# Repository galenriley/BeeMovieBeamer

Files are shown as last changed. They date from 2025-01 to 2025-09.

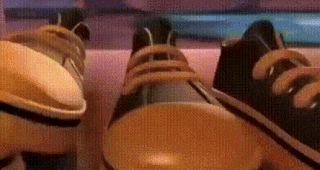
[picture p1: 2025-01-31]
assets/beemovie_wide.gif

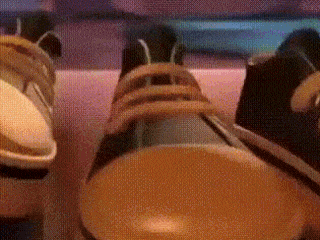
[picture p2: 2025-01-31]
assets/beemovie_full.gif

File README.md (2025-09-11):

# BeeMovieBeamer

A stupid gift for Junior  
based on a [tiktok from @jacuto](https://www.tiktok.com/@jacuto/video/7439527807316790574?lang=en)  
with help from Becca and Don (who don't want to be linked to)

## Safety/Disclaimers

I am an idiot that doesn't know what he is doing with microcontrollers! Lithium batteries are terrifying! And flammable!
It is highly recommended to gently unplug the battery when not in use and store it in a fire safe container away from anything combustible.

BeeMovieBeamer render

## Button Functions

Most functions are accessible via the startup screen. If you're "lost" during operation, press the power button once to restart the device.

- **Power Button** (located on the side of the device, near the USB port)  
  Press to reset/power on and go to the startup screen. Double press to power off.
- **Button 1** (located next to the screen, in the center)  
  Plays The Bee Movie once, then ~~puts the device to sleep~~ disables the screen backlight to conserve battery.
- **Button 2** (located next to the screen, on top if the USB port is oriented upward)  
  Vertically flips the display.  
  *This button only works on the startup screen.
- **Button 3** (located next to the screen, on the bottom if the USB port is oriented upward)  
  Plays The Bee Movie on loop until the device is reset using the Power Button or the battery dies.  
  *This button only works on the startup screen. 
- **Button 4** (located on the side of the device, near the USB port)  
  Resets the "Lifetime Bees Movied" counter on the startup screen.  
  Press once for conformation prompt. Press twice to reset the counter.  
  *This button only works on the startup screen.
  The case allows access to this button using a paperclip or sim ejector tool.

## Disassembly for Safe Storage
  
1. Remove the hand strap.
2. Insert a fingernail or prying tool in the slots on the side of the case.
3. Remove the back panel by sliding it out.
4. _Carefully_ lift the battery, slide out the battery tray, and unplug the battery cable.  
 
## Bill of Materials

- [LILYGO T4 v1.3 with 2.4 inch display](https://lilygo.cc/products/t4?variant=42405660393653)
Be sure to get the Q368 variant. The other is not compatible with the 3d printed case included in this project.
- 3.7V Lipo Batterywith JST GH 1.25mm plug, max dimensions 6.5mm x 40mm x 65mm
[I used this one and replaced the stock plug with one which came packaged with the LILYGO T4 board](https://www.amazon.com/dp/B07S75L945). You could buy a smaller battery with the right plug, and fill the leftover space in the case with some scrap foam to prevent it from rattling around.
- [This micro USB cable fits the case perfectly](https://a.co/d/34nNxp7)
- 1 inch nylon webbing strap and tri-glide buckle (or your own solution, elastic would also work)
- 2x M2 screws

You also need access to a computer to build and deploy the software, 3D printer(s), and you will likely need to solder the battery cable.

## Instructions to Make Your Own

### Buliding the Software
1. [Download and install Visual Studio Code](https://code.visualstudio.com/Download)
2. Open Visual Studio Code and [install PlatformIO IDE](https://platformio.org/install/ide?install=vscode)
3. [Download the project files from GitHub](https://github.com/galenriley/BeeMovieBeamer/archive/refs/heads/main.zip) and unzip somewhere on your computer.
4. From Visual Studio Code, click the PlatformIO icon on the left sidebar (it looks like an ant's head).
5. From the PlatformIO frame, click "Open Project" and navigate to the BeeMovieBeamer folder you unzipped earlier.
6. Connect the LILYGO T4 board to your computer via the micro usb port.
7. Near the bottom of Visual Studio Code, look for these icons. Mouse-over the Check icon, confirm the tooltip says "PlatformIO: Build", and click it.


8. After the Build process is complete, mouse over the Right Arrow icon, confirm the tooltip says "PlatformIO: Upload", and click it. Wait for the upload to complete and the board to reboot and show the software startup screen.

### Fabricating the Bee Movie Beamer
1. Find the 3D files in the project's "/case/" folder (you downloaded these already) and print using your preferred filament and settings. This is left as an exercise for the reader.
The case prints just fine with FDM, though the buttons are tiny and printing with resin would result in a better looking end product.
2. Sand/paint/seal/finish the parts as preferred.
Note: The clearances around the buttons are snug and you may need to sand away some material to achieve a satisfactory final fit, especially around the power button on the side.
3. Set the case on a stable surface and carefully position the buttons in their slots. Tweezers will come in handy.
4. Place the board in the case and secure with 2x screws.
5. If your battery didn't already have a 1.25mm plug, cut off the stock plug and solder the one which came packaged with the board.
Safety warning: Do not let the wires touch when soldering, for explosion and fire and pain reasons.
6. Plug in the battery, route the cable around the battery tray while installing it (the tray is to isolate the battery from being punctured by the IO pins on the board, you could also snip these pins off), and install the back lid of the case.
7. For the hand strap, feed the nylon webbing around the center bar of the triglide buckle and sew to itself.
8. On the case, feed the hand strap from the front to the back through one buckle, across the back lid, from the back to the front through the other buckle, and through both slots in the triglide. Adjust for your hand, cut to fit, then remove the strap to melt the raw end from fraying. Reinstall the strap.

Enjoy!

PS If you make this dumb thing, please tag Instagram @thatgalen, so I can see your creation!

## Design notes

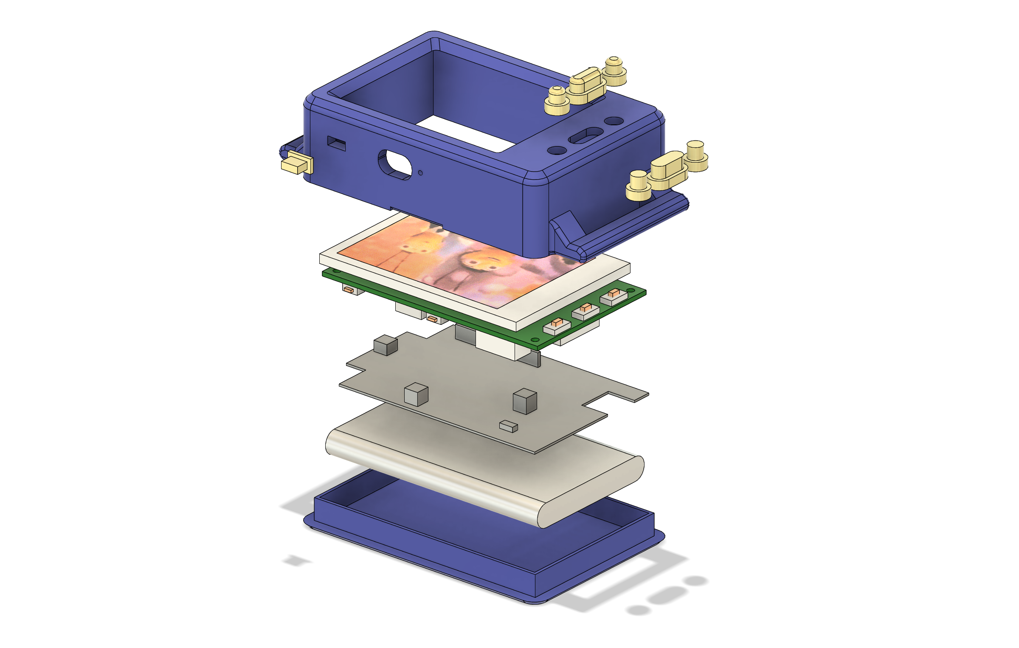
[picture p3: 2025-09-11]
case/exploded_view.png

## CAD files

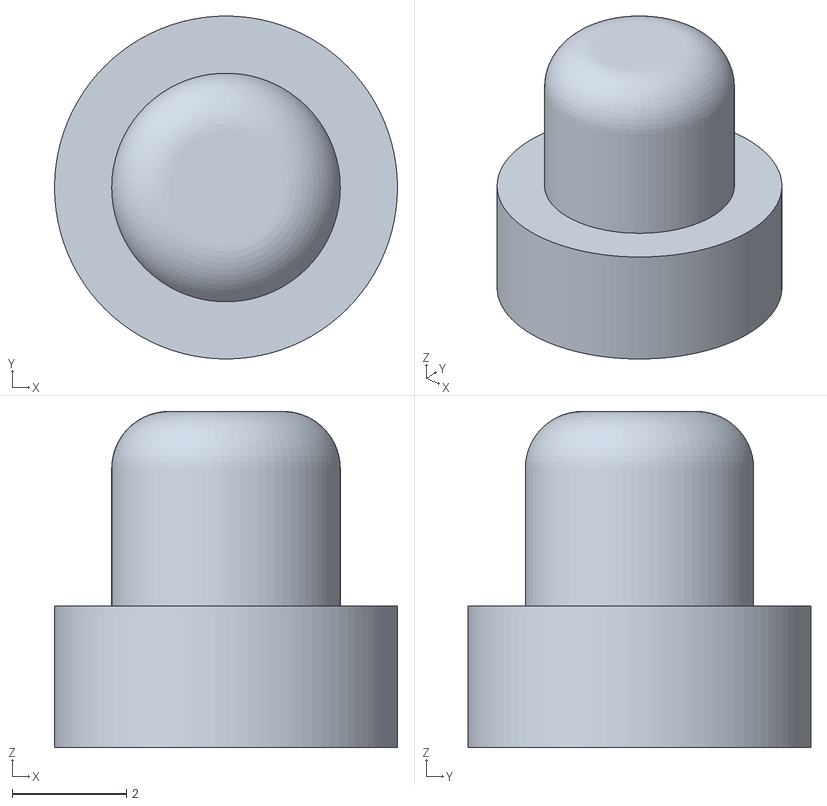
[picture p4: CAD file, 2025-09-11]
case/circle_button_rounded_print_two.stl
6.00 x 6.00 x 5.88

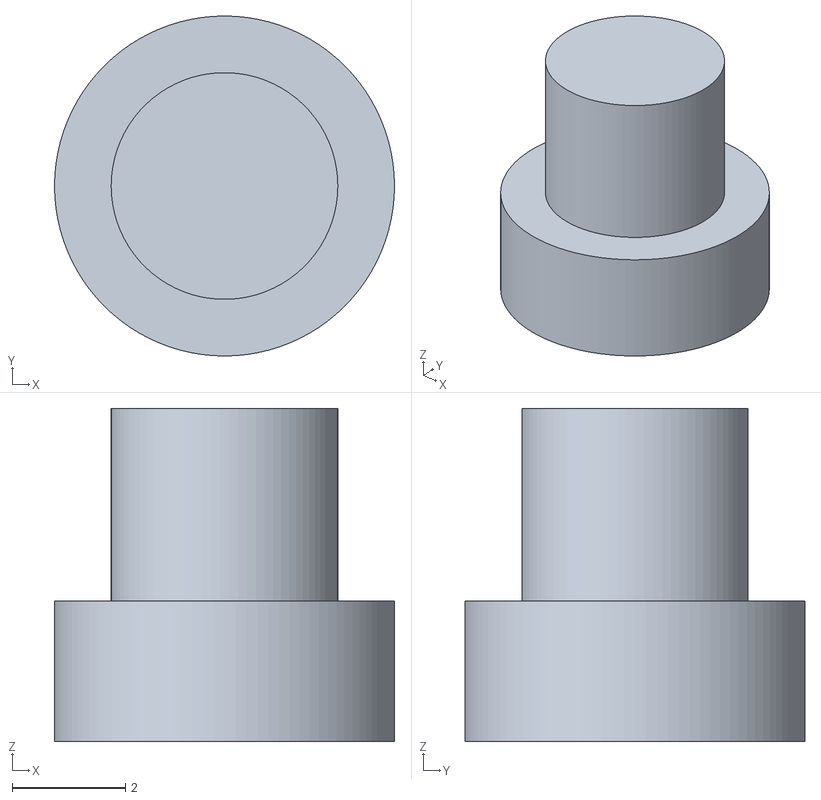
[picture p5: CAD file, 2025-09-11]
case/circle_button_flat_alt_print_two.stl
6.00 x 6.00 x 5.88

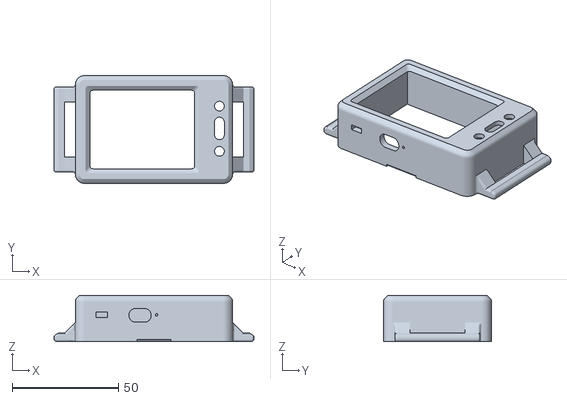
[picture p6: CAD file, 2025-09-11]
case/case.stl
94.0 x 50.7 x 21.8

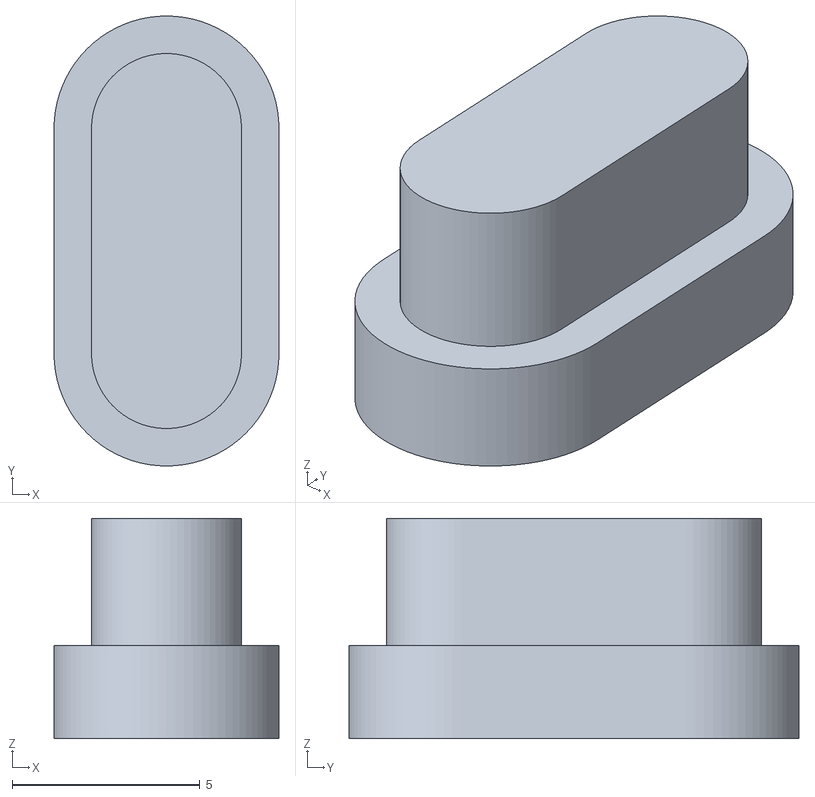
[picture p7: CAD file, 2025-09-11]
case/pill_button_flat_alt.stl
6.00 x 12.0 x 5.88

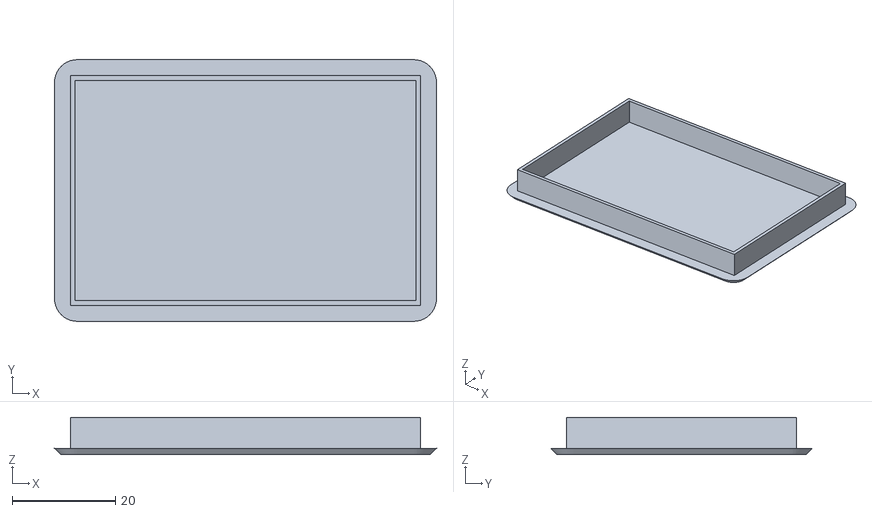
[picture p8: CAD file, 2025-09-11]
case/case_back_lid.stl
74.0 x 50.7 x 7.20

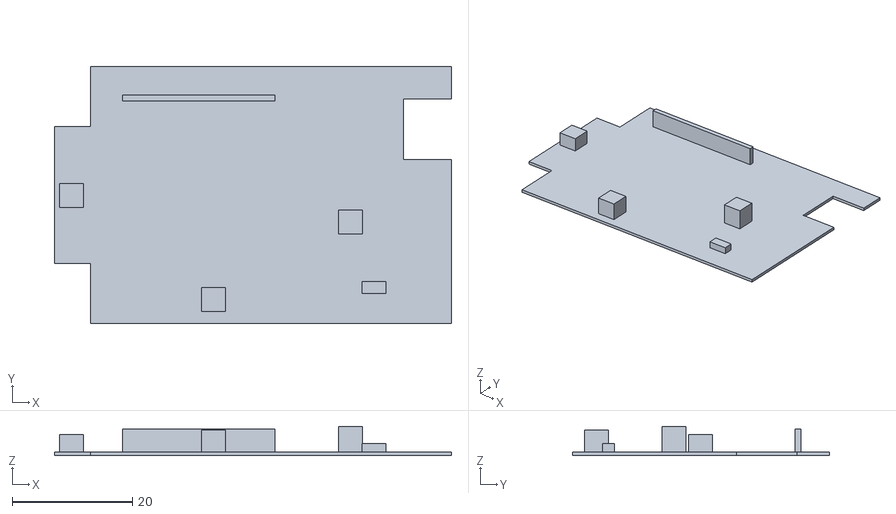
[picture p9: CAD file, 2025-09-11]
case/battery_tray.stl
66.0 x 42.7 x 4.88

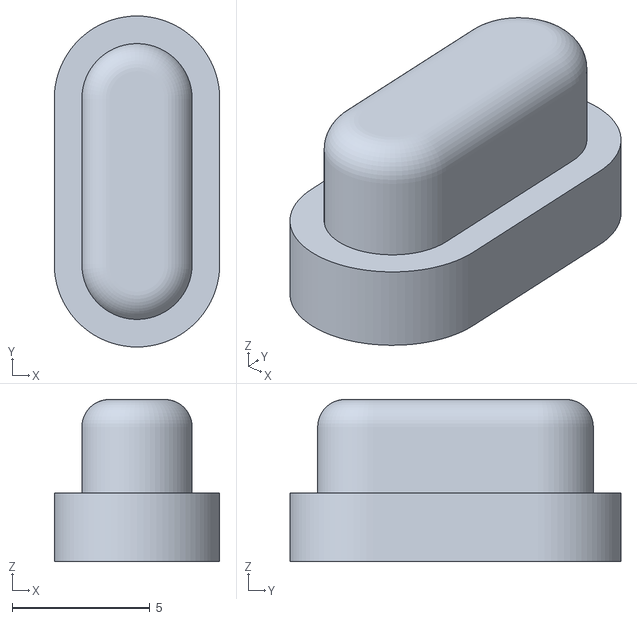
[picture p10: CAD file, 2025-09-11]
case/pill_button_rounded.stl
6.00 x 12.0 x 5.88

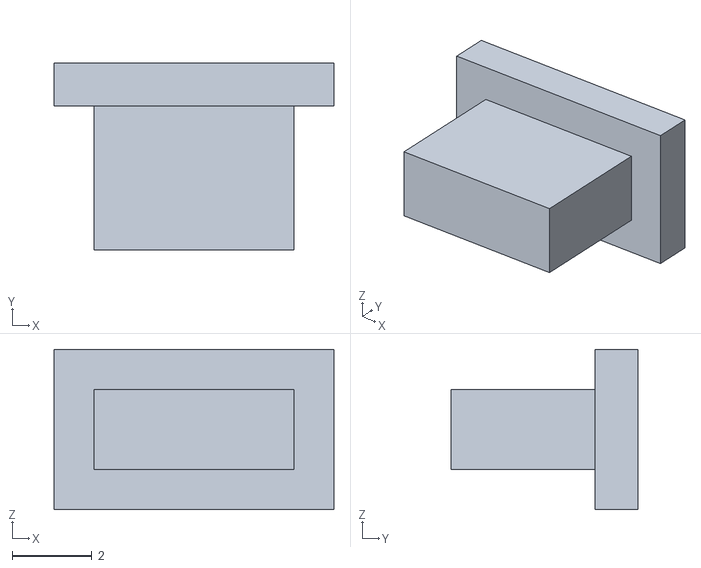
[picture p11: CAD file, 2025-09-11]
case/side_button.stl
7.00 x 4.68 x 4.00

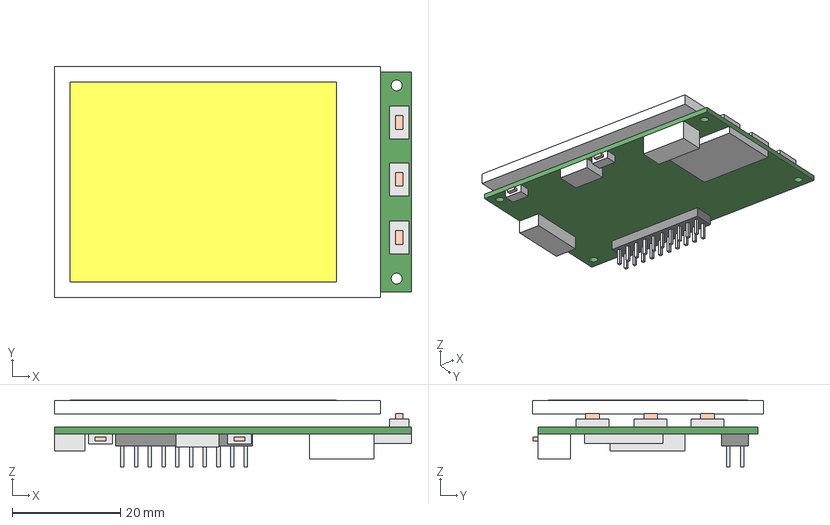
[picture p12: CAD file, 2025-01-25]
case/Lilygo_ttgo_T4_2.4_Model.step
66.0 x 42.7 x 12.3 mm
Display vis area
Display raw
board_raw
Button Pins
USB Con
Button Case
RST Button Case
RST Button Pin
SD Card Holder
Boot Button Case
Boot Button Pin
Antenna
Pinheader
I2C Con
Pinheader Body

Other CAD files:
case/Bee Movie Beamer Case v21.f3d

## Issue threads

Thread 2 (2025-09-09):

Fix deep sleep

galenriley, 2025-09-09:
Deep sleep and waking from the single-Bee button worked, but the device turns off entirely after some unknown amount of time. This makes it impractical for a typical shift wearing a costume at a convention.

I changed the code to disable the sleep and instead only turn off the backlight for battery conservation. As far as I know, it will run for at least 8 hours using the suggested battery, if starting from a full charge.

Investigate deep sleep and see if there's a default time before it powers off that we can edit or disable.

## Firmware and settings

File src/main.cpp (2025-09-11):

#include <Arduino.h>
#include <FS.h>
#include <LittleFS.h>
#include <TFT_eSPI.h>
#include <T4_V13.h>
#include <SPI.h>
#include <Wire.h>
#include <Ticker.h>
#include <Button2.h>
#include <AnimatedGIF.h>

#define IP5306_ADDRESS 0x75

uint8_t state = 0;

TFT_eSPI tft = TFT_eSPI();
RTC_DATA_ATTR int tftRotation = 3;
// determines behavior when waking up from sleep mode
RTC_DATA_ATTR bool hasShownDisplay = false; 
bool pollBattery = false;

Button2 *pBtns = nullptr;
uint8_t g_btns[] =  BUTTONS_MAP;
Ticker btnscanT;

//#include <beemovie_wide.h>
//int yOffset = 35;
#include <beemovie_full.h>
int yOffset = 0;
#define GIF_IMAGE beemovie
AnimatedGIF gif;

String beamCountPath = "/beam_count.txt";
File beamCountFile;
bool beamCountResetPrompt = false;
// log of resets, because Becca insisted
// Note: no counting was done previous to 1/31 but the Bee Movie was certainly beamed a few dozen times during early development and testing and fuckin' around with it
// - 2025/01/31: 27
// - 2025/02/08: 61
// - 2025/08/28: 5041 (after battery benchmarking, before gift presentation at DragonCon)

// adapted from https://github.com/bitbank2/AnimatedGIF/blob/master/examples/TFT_eSPI_memory/GIFDraw.ino
// added yOffset for setting vertical position
void GIFDraw(GIFDRAW *pDraw)
{
    uint8_t *s;
    uint16_t *d, *usPalette;
    int x, y, iWidth, iCount;

    int16_t DISPLAY_WIDTH = tft.width();
    int16_t DISPLAY_HEIGHT = tft.height();

    int BUFFER_SIZE = 320; // Optimum is >= GIF width or integral division of width
    uint16_t usTemp[BUFFER_SIZE];    // Global to support DMA use

    // Display bounds check and cropping
    iWidth = pDraw->iWidth;
    if (iWidth + pDraw->iX > DISPLAY_WIDTH)
    iWidth = DISPLAY_WIDTH - pDraw->iX;
    usPalette = pDraw->pPalette;
    y = pDraw->iY + pDraw->y + yOffset; // current line
    if (y >= DISPLAY_HEIGHT || pDraw->iX >= DISPLAY_WIDTH || iWidth < 1)
    return;

    // Old image disposal
    s = pDraw->pPixels;
    if (pDraw->ucDisposalMethod == 2) // restore to background color
    {
    for (x = 0; x < iWidth; x++)
    {
        if (s[x] == pDraw->ucTransparent)
        s[x] = pDraw->ucBackground;
    }
    pDraw->ucHasTransparency = 0;
    }

    // Apply the new pixels to the main image
    if (pDraw->ucHasTransparency) // if transparency used
    {
        uint8_t *pEnd, c, ucTransparent = pDraw->ucTransparent;
        pEnd = s + iWidth;
        x = 0;
        iCount = 0; // count non-transparent pixels
        while (x < iWidth)
        {
            c = ucTransparent - 1;
            d = &usTemp[0];
            while (c != ucTransparent && s < pEnd && iCount < BUFFER_SIZE )
            {
                c = *s++;
                if (c == ucTransparent) // done, stop
                {
                    s--; // back up to treat it like transparent
                }
                else // opaque
                {
                    *d++ = usPalette[c];
                    iCount++;
                }
            } // while looking for opaque pixels
            if (iCount) // any opaque pixels?
            {
                // DMA would degrtade performance here due to short line segments
                tft.setAddrWindow(pDraw->iX + x, y, iCount, 1);
                tft.pushPixels(usTemp, iCount);
                x += iCount;
                iCount = 0;
            }
            // no, look for a run of transparent pixels
            c = ucTransparent;
            while (c == ucTransparent && s < pEnd)
            {
                c = *s++;
                if (c == ucTransparent)
                    x++;
                else
                    s--;
            }
        }
    }
    else
    {
        s = pDraw->pPixels;

        // Unroll the first pass to boost DMA performance
        // Translate the 8-bit pixels through the RGB565 palette (already byte reversed)
        if (iWidth <= BUFFER_SIZE)
            for (iCount = 0; iCount < iWidth; iCount++) usTemp[iCount] = usPalette[*s++];
        else
            for (iCount = 0; iCount < BUFFER_SIZE; iCount++) usTemp[iCount] = usPalette[*s++];

        tft.setAddrWindow(pDraw->iX, y, iWidth, 1);
        tft.pushPixels(&usTemp[0], iCount);

        iWidth -= iCount;
        // Loop if pixel buffer smaller than width
        while (iWidth > 0)
        {
            // Translate the 8-bit pixels through the RGB565 palette (already byte reversed)
            if (iWidth <= BUFFER_SIZE)
                for (iCount = 0; iCount < iWidth; iCount++) usTemp[iCount] = usPalette[*s++];
            else
                for (iCount = 0; iCount < BUFFER_SIZE; iCount++) usTemp[iCount] = usPalette[*s++];

            tft.pushPixels(&usTemp[0], iCount);

            iWidth -= iCount;
        }
    }
}

// Button handling functions, from lilygo example
void button_handle(uint8_t gpio)
{
    switch (gpio) {
#ifdef BUTTON_1
    case BUTTON_1: {
        state = 1;
    }
    break;
#endif

#ifdef BUTTON_2
    case BUTTON_2: {
        state = 2;
    }
    break;
#endif

#ifdef BUTTON_3
    case BUTTON_3: {
        state = 3;
    }
    break;
#endif

#ifdef BUTTON_4
    case BUTTON_4: {
        state = 4;
    }
    break;
#endif
    default:
        break;
    }
}

void button_callback(Button2 &b)
{
    for (int i = 0; i < sizeof(g_btns) / sizeof(g_btns[0]); ++i) {
        if (pBtns[i] == b) {
            Serial.printf("btn: %u press\n", pBtns[i].getAttachPin());
            button_handle(pBtns[i].getAttachPin());
        }
    }
}

void button_init()
{
    uint8_t args = sizeof(g_btns) / sizeof(g_btns[0]);
    pBtns = new Button2 [args];
    for (int i = 0; i < args; ++i) {
        pBtns[i] = Button2(g_btns[i]);
        pBtns[i].setPressedHandler(button_callback);
    }
}

void button_loop() {
    for (int i = 0; i < sizeof(g_btns) / sizeof(g_btns[0]); ++i) {
        pBtns[i].loop();
    }
}

// "Lifetime Bees Movied" counter is stored in a local file
String getBeamCount()
{
    beamCountFile = LittleFS.open(beamCountPath, "r", false);
    if (beamCountFile.available())
    {
        String value = beamCountFile.readString();
        value.trim();
        beamCountFile.close();

        return value;
    }

    return "Error getting " + beamCountPath; 
}

void displayResetBeamCountConfirmation()
{
    beamCountResetPrompt = true;

    tft.setTextColor(TFT_RED, TFT_BLACK);
    tft.fillScreen(TFT_BLACK);
    tft.setCursor(0, 0);
    tft.setTextSize(2);
    tft.println("Do you want to reset the \"Lifetime Bees Movied\" counter to zero? Press button again to confirm.");
}

void resetBeamCount()
{
    tft.setTextColor(TFT_RED, TFT_BLACK);
    tft.fillScreen(TFT_BLACK);
    tft.setCursor(0, 0);
    tft.setTextSize(2);
    tft.println("Resetting \"Lifetime Bees Movied\" counter to zero.");
    tft.println("(Previously " + getBeamCount() + ")");

    Serial.println("Resetting \"Lifetime Bees Movied\" counter to zero.");
    Serial.println("(Previously " + getBeamCount() + ")");
    beamCountFile = LittleFS.open(beamCountPath, "w", true);
    beamCountFile.println("0");
    beamCountFile.close();

    beamCountResetPrompt = false;
}

void incrementBeamCount()
{
    beamCountFile = LittleFS.open(beamCountPath, "r+", false);
    String value = beamCountFile.readString();
    String incremented = String(value.toInt() + 1);
    beamCountFile.seek(0, SeekSet);
    beamCountFile.println(incremented);
    beamCountFile.close();
}

void sleep()
{
    //tft.writecommand(ST7735_SLPIN);

    // Sleep disabled for now. See notes in setup() for more info.
    // uncomment only this line and comment out two backlight lines below to re-enable sleep
    //esp_deep_sleep_start();

    tft.fillScreen(TFT_BLACK);
    digitalWrite(TFT_BL, LOW); // disable TFT backlight
}

void flipDisplay()
{
    if (1 == tftRotation)
        tftRotation = 3;
    else if (3 == tftRotation)
        tftRotation = 1;
    tft.setRotation(tftRotation);
    tft.setTextColor(TFT_YELLOW, TFT_BLACK);
    tft.fillScreen(TFT_BLACK);
    tft.setTextSize(3);
    tft.setTextDatum(TC_DATUM);
    tft.drawString("^^^", tft.width() / 2, 0);
    tft.setTextDatum(MC_DATUM);
    tft.drawString("this side up", tft.width() / 2, tft.height() / 2);
}

void beeMovie()
{
    if (gif.open((uint8_t *)GIF_IMAGE, sizeof(GIF_IMAGE), GIFDraw))
    {
        //Serial.printf("Successfully opened GIF; Canvas size = %d x %d\n", gif.getCanvasWidth(), gif.getCanvasHeight());
        tft.startWrite(); // The TFT chip select is locked low
        while (gif.playFrame(true, NULL))
        {
            yield();
        }
        gif.close();
        tft.endWrite(); // Release TFT chip select for other SPI devices
    }

    incrementBeamCount();
}

// Examples from https://github.com/rynskyi/IP5306
bool getBatteryExists()
{
    Wire.begin(I2C_SDA,I2C_SCL);
    Wire.beginTransmission(IP5306_ADDRESS);
    uint8_t result = Wire.endTransmission();
    if (0 == result)
    {
        //Serial.println("Detected IP5306 battery");
        return true;
    }
    else
    {
        //Serial.println("Did not detect IP5306 battery?");
    }

    return false;
}

bool getIsChargerConnected()
{
    if (getBatteryExists())
    {
        Wire.begin(I2C_SDA,I2C_SCL);
        Wire.beginTransmission(IP5306_ADDRESS);
        Wire.write(0x70);
        if (Wire.endTransmission(false) == 0 && Wire.requestFrom(IP5306_ADDRESS, 1))
        {
            return (Wire.read() & (1 << 3)) ? true : false;
        }
    }
}

bool getIsChargeFull()
{
    if (getBatteryExists())
    {
        Wire.begin(I2C_SDA,I2C_SCL);
        Wire.beginTransmission(IP5306_ADDRESS);
        Wire.write(0x71);
        if (Wire.endTransmission(false) == 0 && Wire.requestFrom(IP5306_ADDRESS, 1))
        {
            return (Wire.read() & (1 << 3)) ? false : true;
        }
    }
}

uint8_t getBatteryLevel()
{
    if (getBatteryExists())
    {
        Wire.begin(I2C_SDA,I2C_SCL);
        Wire.beginTransmission(IP5306_ADDRESS);
        Wire.write(0x78);
        if (Wire.endTransmission(false) == 0 && Wire.requestFrom(IP5306_ADDRESS, 1))
        {
            switch (Wire.read() & 0xF0)
            {
                case 0xE0: return 25;
                case 0xC0: return 50;
                case 0x80: return 75;
                case 0x00: return 100;
                default: return 0;
            }
        }
    }
}

void drawBatteryStatus()
{
    if (pollBattery && getBatteryExists())
    {
        tft.setTextColor(TFT_MAGENTA, TFT_BLACK);
        tft.setTextDatum(BL_DATUM); // for some reason this isn't working
        tft.setTextSize(2);
        String battery = "";
        if (getIsChargerConnected())
            battery = "Charging";
        else
            battery = "Battery " + String(getBatteryLevel()) + "%";
        tft.drawString(battery, 0, tft.height());
    }
}

void displayStartupScreen()
{
    tft.fillScreen(TFT_BLACK);
    tft.setCursor(0, 0);
    tft.setTextFont(1);
    tft.setTextSize(2);
    tft.setTextColor(TFT_YELLOW, TFT_BLACK);
    tft.setTextDatum(TL_DATUM);
    tft.println("Hey disciples, has anyone seen The Bee Movie?");
    tft.println();

    tft.setTextSize(1);
    tft.setTextColor(TFT_MAGENTA, TFT_BLACK);
    tft.println("(a stupid gift for Junior)");
    
    tft.setTextDatum(ML_DATUM); // for some reason this isn't working
    tft.setTextColor(TFT_CYAN, TFT_BLACK);
    tft.println();
    tft.println();
    tft.println();
    tft.println();
    tft.println("project info:");
    tft.println("https://github.com/galenriley/BeeMovieBeamer");
    tft.println("based on a tiktok post by @jacuto");
    tft.println("with help from Becca and Don");
    tft.println();
    tft.println();
    tft.println();
    tft.println("Lifetime Bees Movied: " + getBeamCount());
    
    pollBattery = true;
    drawBatteryStatus();

    hasShownDisplay = true;
}

void setup() {
    Serial.begin(115200);
    // delay(1000); // why is this delay here in every example?

    /*
        TODO: Device eventually powers off when in deep sleep mode. No time to troubleshoot exactly why,
        but requiring reboots at DragonCon is inconvenient. Commenting this out for now.

        The good news is we have plenty of battery to just turn the screen off/on in lieu of lack of sleep
    */ 
    //esp_sleep_enable_ext1_wakeup(((uint64_t)(((uint64_t)1) << BUTTON_1)), ESP_EXT1_WAKEUP_ALL_LOW);

    if(getBatteryExists())
    {
        Serial.println("Charger connected?");
        Serial.println(getIsChargerConnected());

        Serial.println("Charge full?");
        Serial.println(getIsChargeFull());

        Serial.println("Battery level?");
        Serial.println(getBatteryLevel());
    }

    tft.init();
    tft.setRotation(tftRotation);
    tft.fillScreen(TFT_BLACK);

    button_init();
    btnscanT.attach_ms(30, button_loop);

    if (!LittleFS.begin(true))
    {
        Serial.println("LittleFS Mount Failed");
        return;
    }
    else
    {        
        // initialize new beam_count.txt
        if (!LittleFS.exists(beamCountPath))
        {
            Serial.println(beamCountPath + " does not exist, creating new counter for \"Lifetime Bees Movied\"");
            
            tft.setTextColor(TFT_RED, TFT_BLACK);
            tft.setCursor(0,0);
            tft.setTextFont(1);
            tft.setTextSize(2);
            tft.println(beamCountPath + " does not exist, creating new counter for \"Lifetime Bees Movied\"");
            
            resetBeamCount();
            // hold on this screen for 5s before moving on
            delay(5000);
        }
    }

    gif.begin(BIG_ENDIAN_PIXELS);

    // setup() runs on boot or when waking from sleep, play gif immediately if waking
    if (!hasShownDisplay)
    {
        displayStartupScreen();
    }
    else
    {
        // Using backlight off/on instead of sleep
        digitalWrite(TFT_BL, HIGH); // enable TFT backlight

        beeMovie();   

        // Sleep disabled for now. See notes in setup() for more info.
        sleep();
    }
}


void loop() {
    switch (state) {
    case 1:
        state = 0;

        // reset state stuff
        pollBattery = false;
        beamCountResetPrompt = false;

        // Using backlight off/on instead of sleep
        digitalWrite(TFT_BL, HIGH); // enable TFT backlight
        
        beeMovie();

        // Sleep disabled for now. See notes in setup() for more info.
        sleep();

        break;
    case 2:
        state = 0;

        // reset state stuff
        pollBattery = false;
        beamCountResetPrompt = false;

        // Using backlight off/on instead of sleep
        digitalWrite(TFT_BL, HIGH); // enable TFT backlight
        
        flipDisplay();

        break;
    case 3:
        state = 0;

        // reset state stuff
        pollBattery = false;
        beamCountResetPrompt = false;

        // Using backlight off/on instead of sleep
        digitalWrite(TFT_BL, HIGH); // enable TFT backlight

        // infinite mode!
        while (true)
            beeMovie();

        break;
    case 4:
        state = 0;
        pollBattery = false;

        if (!beamCountResetPrompt)
            displayResetBeamCountConfirmation();
        else
            resetBeamCount();

        break;
    default:
        state = 0;
        break;
    }

    if (pollBattery)
        drawBatteryStatus();
}

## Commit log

2025-01-16 add Button2 lib from https://github.com/Xinyuan-LilyGO/LilyGo_Txx
2025-01-17 sample code from https://github.com/Xinyuan-LilyGO/LilyGo_Txx
2025-01-18 added init screen and also changing tft rotation on button4 press
2025-01-25 step file from https://github.com/Xinyuan-LilyGO/LilyGo_Txx/tree/master/3D_file
    [00_asm-180625.stp]
2025-01-25 board step file from https://www.thingiverse.com/thing:6239819
    [Lilygo_ttgo_T4_2.4_Model.step]
2025-01-31 change initial rotation to 3, southpaw by default
    [lilygo ttgo t4 2.4in case v6.f3d]
2025-02-01 add loop count reset
    [main.cpp]
2025-02-05 swap button functions
2025-02-09 confirm before counter reset, and various styling changes
    [main.cpp]
2025-02-09 remove sample case
    [00_asm-180625.stp]
2025-02-10 first atttempt at battery stuff
2025-02-10 condition battery check
2025-02-10 poll battery in loop()
2025-02-10 battery detection just doesn't work well, this is a simplified form
    [main.cpp]
2025-02-11 added link reference for battery logic
2025-08-09 Sleep mode doesn't fully work like I want it to, disabling screen backlight instead
    [main.cpp]
2025-08-31 Update README.md
    Added link to micro USB cable which fits the case
2025-09-11 add case STL files
    [Bee Movie Beamer Case v21.f3d, battery_tray.stl, case.stl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]
